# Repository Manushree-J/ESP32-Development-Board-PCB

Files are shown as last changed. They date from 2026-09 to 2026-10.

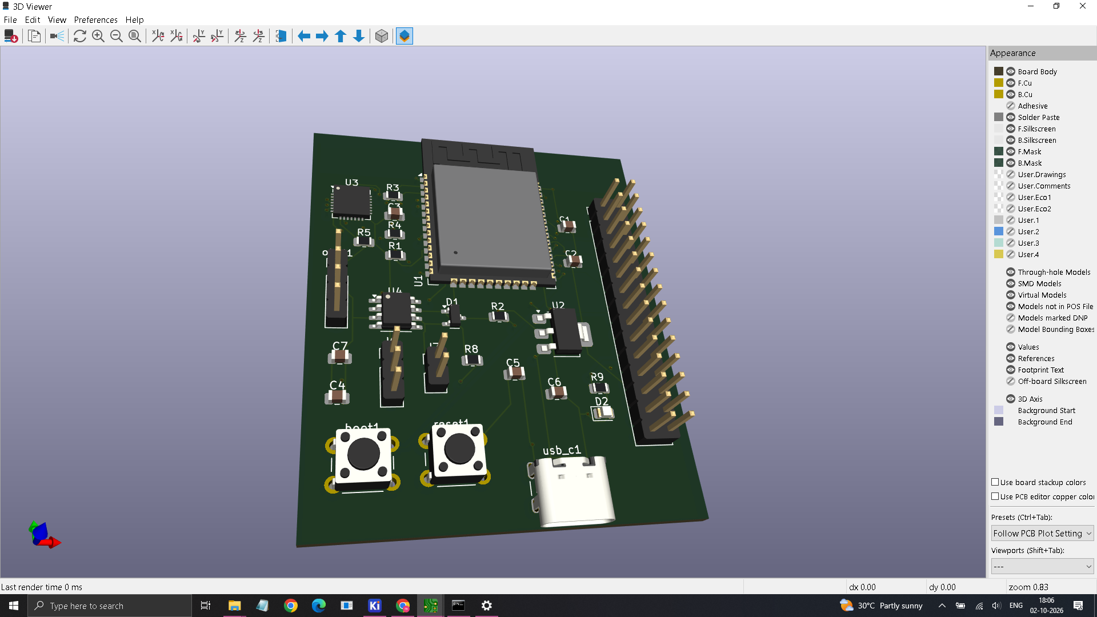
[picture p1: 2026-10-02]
images/3D_view.png

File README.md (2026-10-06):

# ESP32 Development Board — 4-Layer PCB

A custom ESP32 development board designed in KiCad 9, built around the **ESP32-WROOM-32E** module.

The board combines USB programming, regulated power, wireless connectivity, CAN communication, and common embedded interfaces into a compact development platform.

---

## Overview

The ESP32 Development Board is designed as a general-purpose embedded development platform.

The board provides:

- ESP32-WROOM-32E microcontroller module
- Integrated Wi-Fi and Bluetooth
- USB-C interface
- CP2102N USB-to-UART bridge
- AMS1117-3.3 voltage regulator
- I²C interface
- SPI interface
- UART interfaces
- CAN interface
- OLED interface
- Boot and Reset push buttons
- User LED
- 30-pin GPIO expansion header
- Four-layer PCB stackup
- Ground plane on the inner layer
- CAN protection and selectable termination

---

## Hardware Architecture

The main system is centered around the **ESP32-WROOM-32E**.

### Main Blocks

```text
                    ┌──────────────────────┐
                    │      USB-C INPUT     │
                    └──────────┬───────────┘
                               │
                    ┌──────────▼───────────┐
                    │      CP2102N         │
                    │    USB-to-UART       │
                    └──────────┬───────────┘
                               │ UART
                               │
                    ┌──────────▼───────────┐
                    │    ESP32-WROOM-32E   │
                    │                      │
                    │ Wi-Fi + Bluetooth    │
                    │ GPIO / UART / SPI    │
                    │ I²C / CAN           │
                    └───────┬─────┬────────┘
                            │     │
               ┌────────────┘     └─────────────┐
               │                                │
        ┌──────▼──────┐                  ┌──────▼──────┐
        │   OLED/I²C  │                  │    CAN      │
        │             │                  │ SN65HVD230  │
        └─────────────┘                  └──────┬──────┘
                                               │
                                         CANH / CANL

                    ┌──────────────────────┐
                    │    AMS1117-3.3      │
                    │    Power Supply     │
                    └──────────────────────┘

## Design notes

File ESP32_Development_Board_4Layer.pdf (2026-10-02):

ESP32 DEVELOPMENT BOARD | FOUR-LAYER TECHNICAL DATASHEET

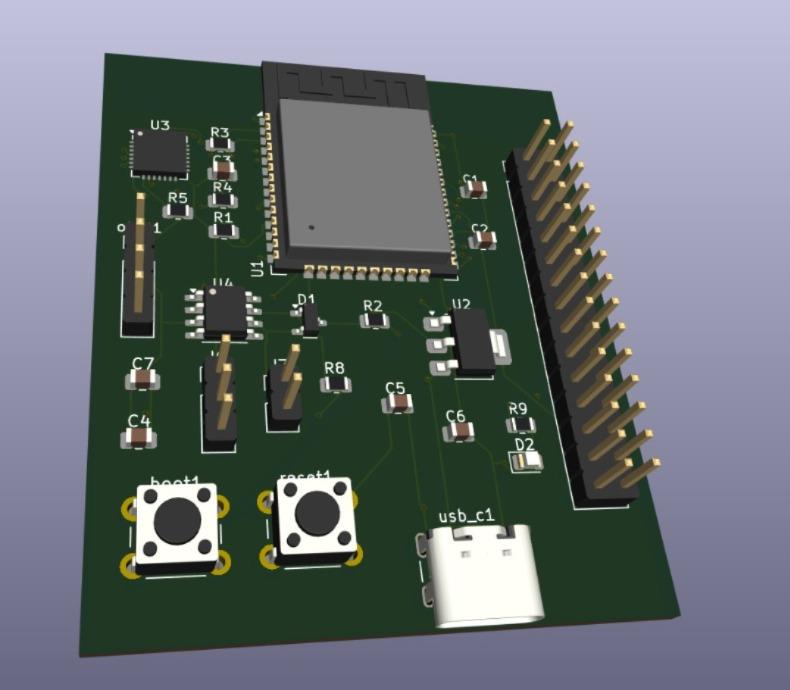
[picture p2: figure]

ESP32 Development Board • Four-Layer PCB

# ESP32 DEVELOPMENT BOARD

## FOUR-LAYER TECHNICAL DATASHEET

A custom embedded development platform with USB programming, wireless connectivity, peripheral interfaces and CAN communication.

# 01 | Product Overview

The ESP32 Development Board is a custom four-layer PCB built around the ESP32-WROOM-32E module. It combines power regulation, USB-to-UART connectivity and common embedded interfaces in a single development platform.

FUNCTION | IMPLEMENTATION
Microcontroller | ESP32-WROOM-32E with integrated Wi-Fi and Bluetooth
USB | USB-C connector with CP2102N USB-to-UART bridge
Power | USB input and AMS1117-3.3 regulator
Display | OLED connector
Communication | UART, SPI, I²C and CAN
CAN hardware | SN65HVD230 transceiver, NUP2105L protection and selectable 120 Ω termination
Expansion | 30-pin, 2.54 mm GPIO header
User controls | Boot and Reset push buttons; user LED

# 02 | Four-Layer PCB Layout

The following views are taken from the current four-layer KiCad PCB design.

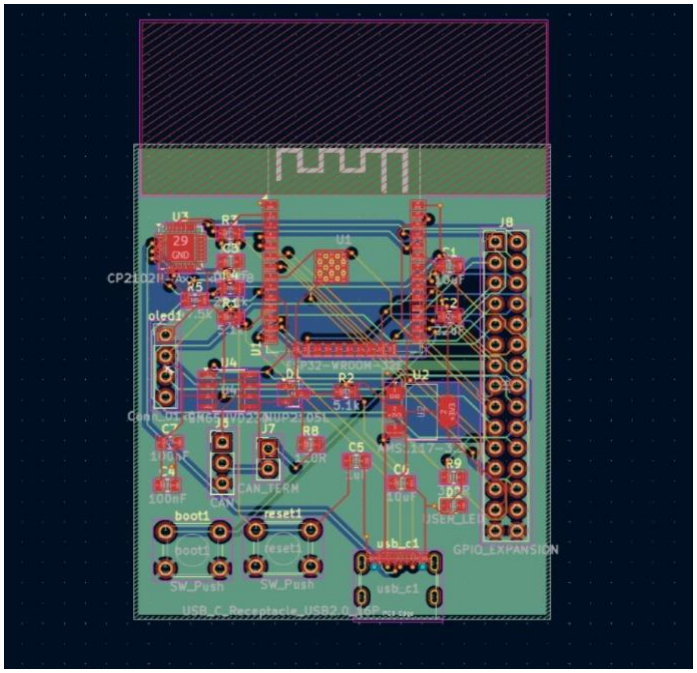
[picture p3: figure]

Figure 1. Current PCB layout with F.Cu selected.

# 03 | F.Cu — Top Copper

Top copper routing and component-side copper features.

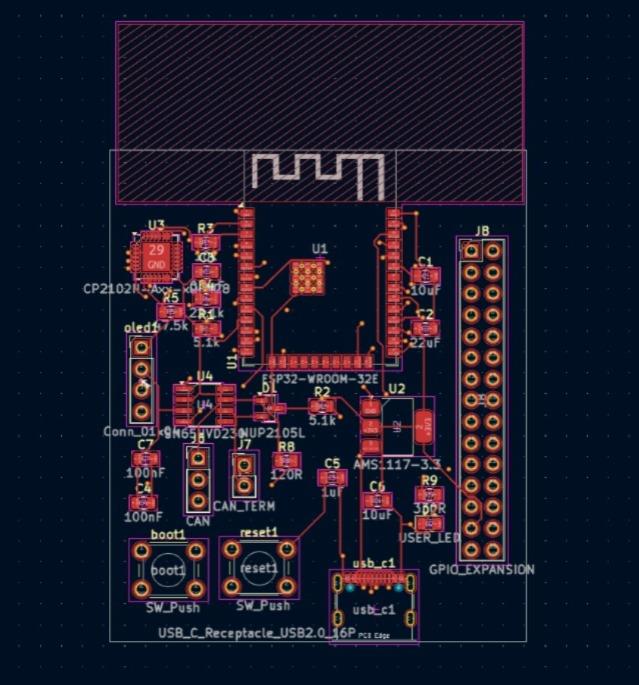
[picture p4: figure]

Current four-layer PCB view.

# 04 | In1.Cu — Inner Ground Layer

Inner copper layer configured as the ground plane.

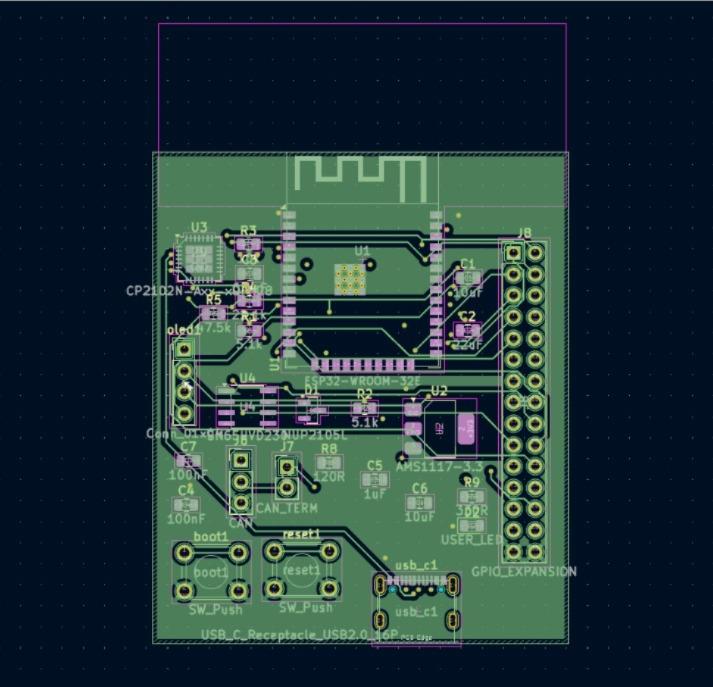
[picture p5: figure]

Current four-layer PCB view.

# 05 | In2.Cu — Inner Routing Layer

Inner copper layer used for additional signal and power routing.

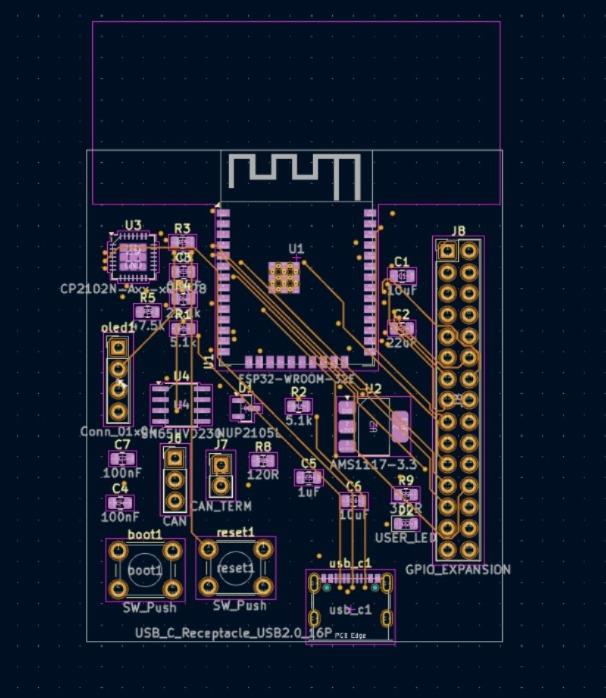
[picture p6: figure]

Current four-layer PCB view.

# 06 | B.Cu — Bottom Copper

Bottom copper routing and ground copper.

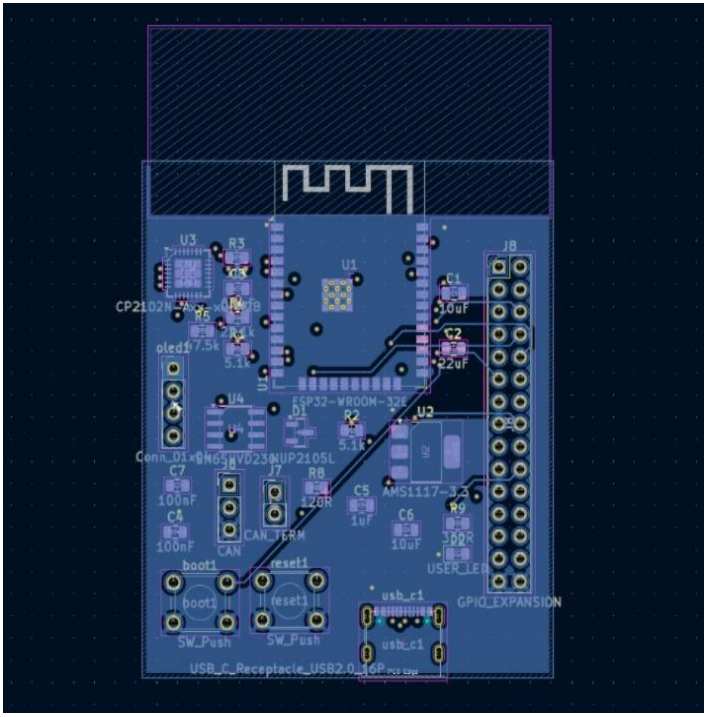
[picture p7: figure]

Current four-layer PCB view.

# 07 | Hardware Architecture

USB-C provides the board input and host connection. The CP2102N provides the USB-to-UART bridge for the ESP32 serial programming path. The AMS1117-3.3 generates the 3.3 V rail. The ESP32 module provides processing and integrated wireless functionality.

## Interface Summary

INTERFACE | SIGNALS / IMPLEMENTATION | NOTES
UART0 | GPIO1 (TX), GPIO3 (RX) | CP2102N serial path
UART2 | GPIO16, GPIO17 | Available through GPIO expansion
I²C | GPIO21 (SDA), GPIO22 (SCL) | OLED / external peripherals
SPI | GPIO18, GPIO19, GPIO23 | Available through GPIO expansion
CAN | GPIO25 / GPIO26; SN65HVD230 | CANH, CANL and GND connector
GPIO | J8, 2×15 header | 26 GPIOs plus power and ground

## Schematic

The schematic is shared by the two-layer and four-layer PCB versions; the four-layer version changes the PCB copper stackup and routing, not the circuit schematic.

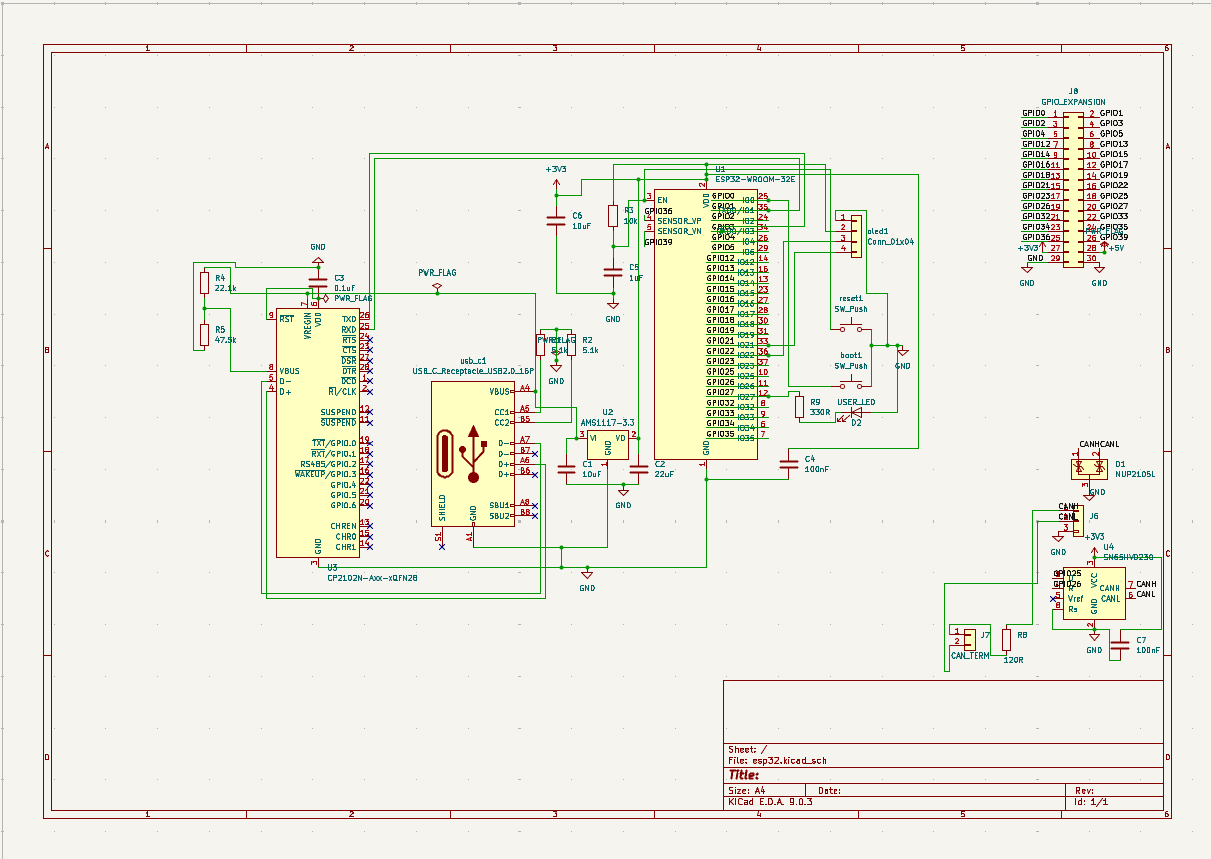
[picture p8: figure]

Figure 2. Shared circuit schematic.

# 08 | GPIO Expansion

J8 is a 30-pin, 2.54 mm-pitch header that exposes the available GPIOs and power connections. GPIO6–GPIO11 are reserved for the module's internal flash interface and are not brought out.

PIN | SIGNAL | PIN | SIGNAL
1 | GPIO0 | 16 | GPIO22
2 | GPIO1 | 17 | GPIO23
3 | GPIO2 | 18 | GPIO25
4 | GPIO3 | 19 | GPIO26
5 | GPIO4 | 20 | GPIO27
6 | GPIO5 | 21 | GPIO32
7 | GPIO12 | 22 | GPIO33
8 | GPIO13 | 23 | GPIO34
9 | GPIO14 | 24 | GPIO35
10 | GPIO15 | 25 | GPIO36
11 | GPIO16 | 26 | GPIO39
12 | GPIO17 | 27 | +3V3
13 | GPIO18 | 28 | +5V
14 | GPIO19 | 29 | GND
15 | GPIO21 | 30 | GND

GPIO34, GPIO35, GPIO36 and GPIO39 are input-only. GPIO0 is used by the boot control circuit. GPIO1 and GPIO3 are shared with the USB-to-UART programming path.

# 09 | Power and CAN

## Power

USB-C supplies the board input. The AMS1117-3.3 regulator generates the 3.3 V rail. Local capacitors provide regulator and device decoupling.

REFERENCE | VALUE / DEVICE | FUNCTION
U2 | AMS1117-3.3 | 3.3 V regulator
C1 | 1 µF | Regulator input-side capacitance
C2 | 22 µF | Regulator output-side bulk capacitance
C4 | 100 nF | ESP32/local decoupling
C6 | 10 µF | Local bulk decoupling
C7 | 100 nF | CAN transceiver decoupling

## CAN Interface

The CAN interface uses an SN65HVD230 transceiver connected to the ESP32 through GPIO25 and GPIO26. CANH and CANL are available at the external CAN connector. A NUP2105L device provides CAN-line protection.

REFERENCE | DEVICE / VALUE | FUNCTION
U4 | SN65HVD230 | CAN physical-layer transceiver
NUP2105L | Protection device | CANH / CANL protection
R8 | 120 Ω | Termination resistor
J7 | CAN_TERM | Selectable termination jumper
J6 | CAN connector | CANH / CANL / GND

When the termination jumper is installed, the 120 Ω resistor is connected between CANH and CANL. The transceiver RS pin is tied to GND for high-speed mode; Vref is left floating.

# 10 | PCB Stackup & Design Status

COPPER LAYER | ROLE
F.Cu | Top copper — component-side routing
In1.Cu | Inner copper — GND plane
In2.Cu | Inner copper — additional signal/power routing
B.Cu | Bottom copper — routing and GND copper zone

Configured board thickness: 1.6 mm. Copper thickness: 0.035 mm per copper layer.

## Design Verification

ITEM | RECORDED STATUS
Schematic ERC | Completed; no errors or warnings reported
PCB connectivity | 0 unconnected items; 0 unrouted connections
Copper zones | Filled
Hardware validation | Fabrication and physical testing have not been performed

## Document Information

FIELD | VALUE
Project | ESP32 Development Board
MCU module | ESP32-WROOM-32E
EDA tool | KiCad 9
PCB version | Four-layer
Schematic | Shared with two-layer version
Repository | github.com/Manushree-J/ESP32-Development-Board-PCB

This datasheet documents the PCB design. Electrical performance and operation should be confirmed through fabrication and hardware testing.

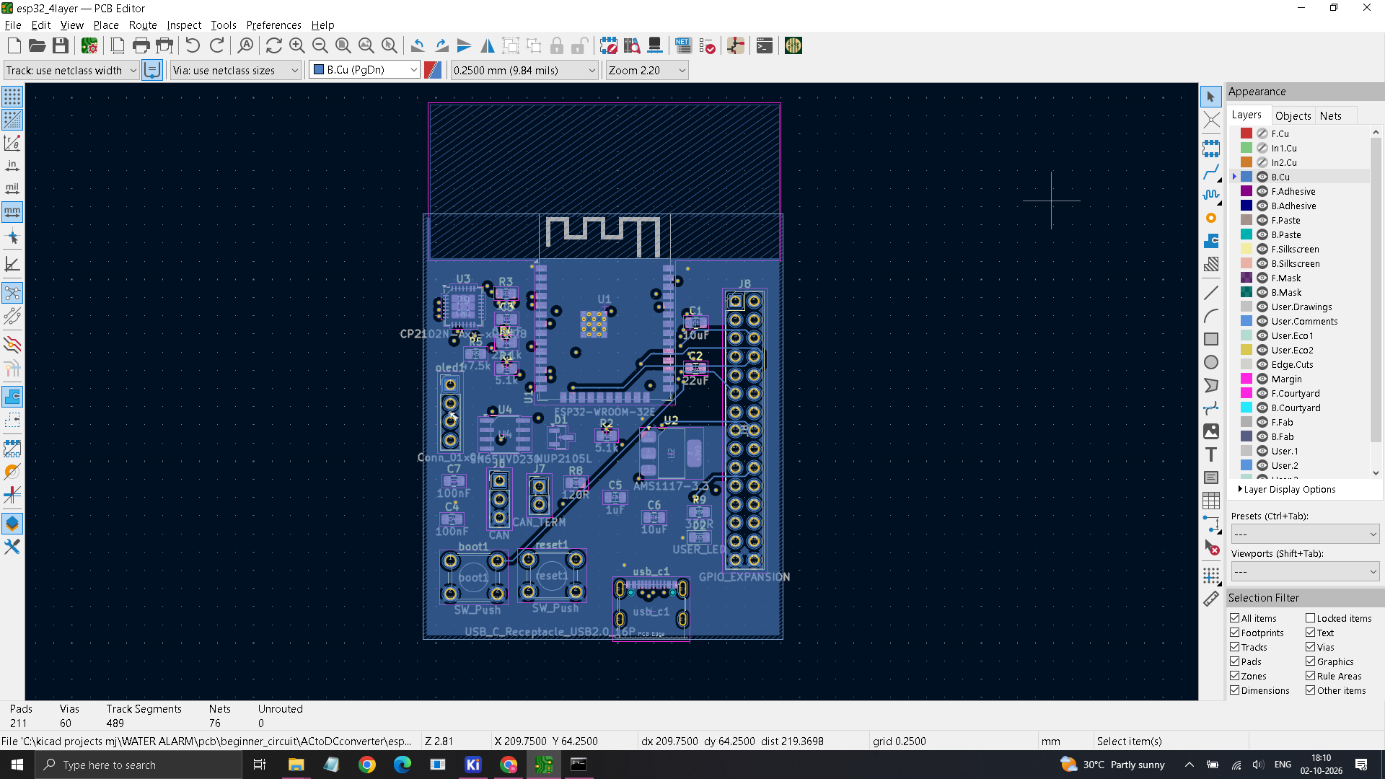
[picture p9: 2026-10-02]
images/bottom_layer.png

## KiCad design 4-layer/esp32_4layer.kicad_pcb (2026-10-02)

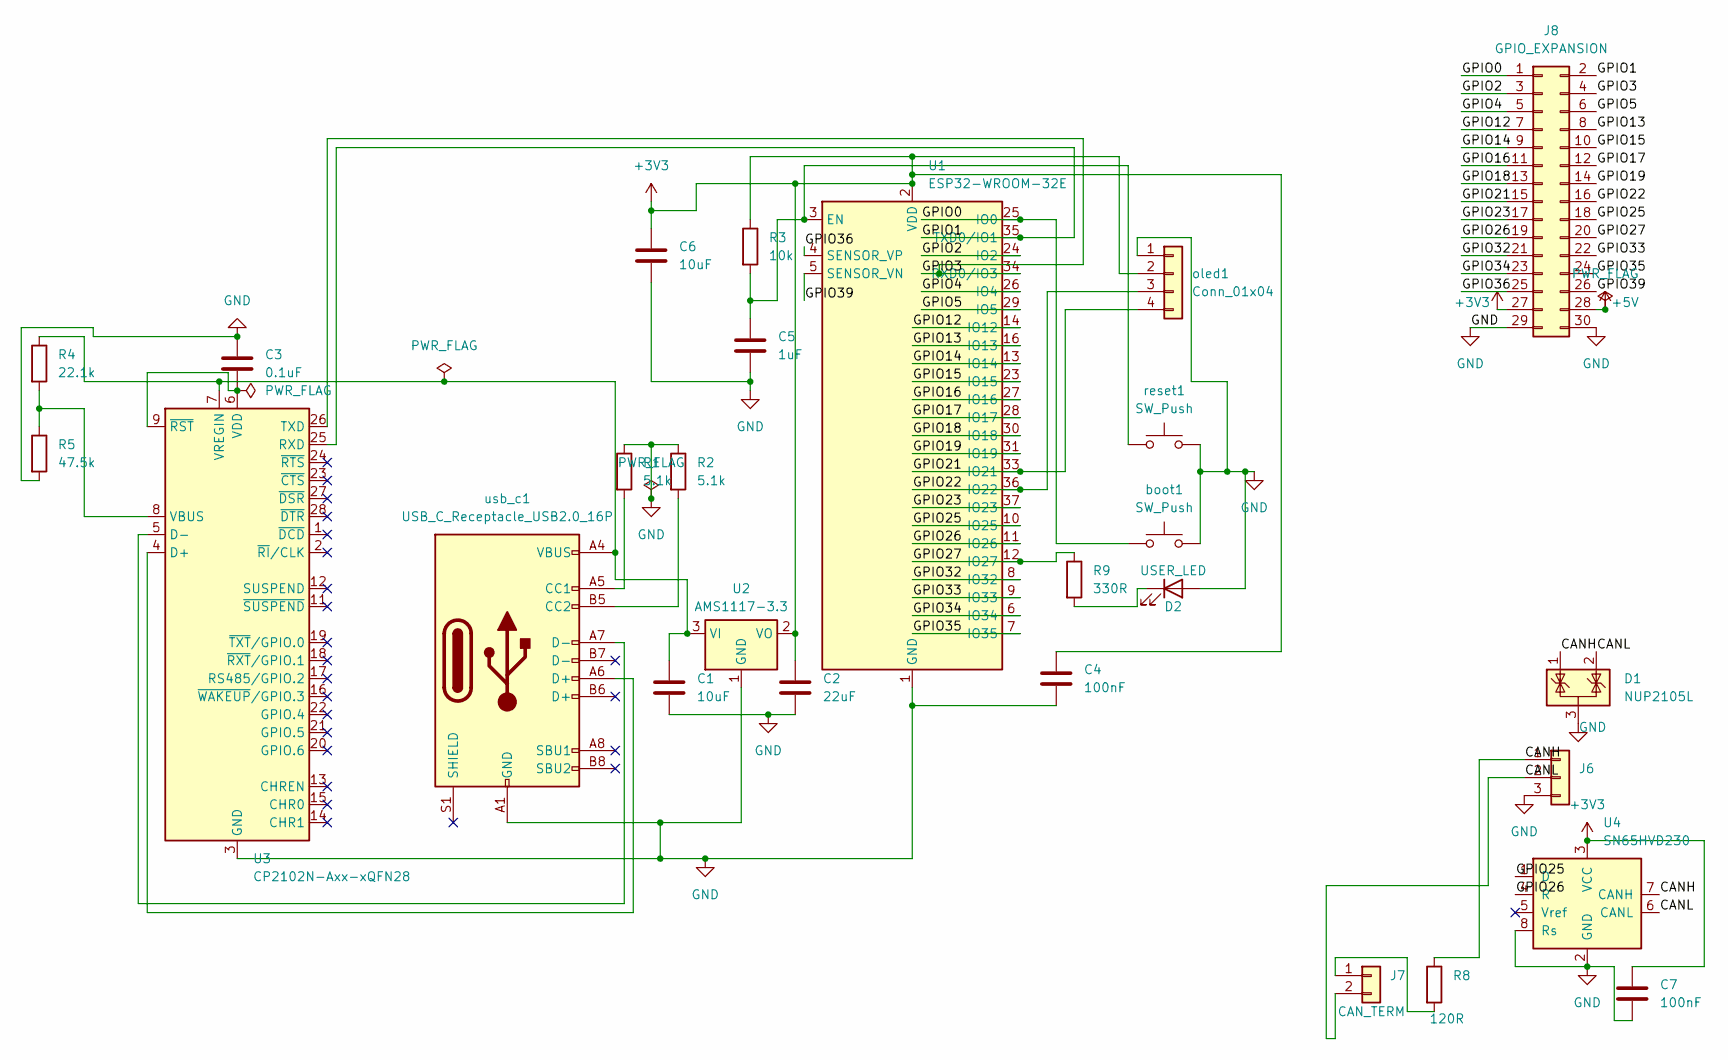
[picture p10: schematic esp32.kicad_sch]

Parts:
C1, C6: 10uF; C_0805_2012Metric
C2: 22uF; C_0805_2012Metric
C3: 0.1uF; C_0805_2012Metric
C4, C7: 100nF; C_0805_2012Metric
C5: 1uF; C_0805_2012Metric
D1: NUP2105L; SOT-23
D2: USER_LED; LED_0805_2012Metric
J6: CAN; PinHeader_1x03_P2.54mm_Vertical
J7: CAN_TERM; PinHeader_1x02_P2.54mm_Vertical
J8: GPIO_EXPANSION; PinHeader_2x15_P2.54mm_Vertical
R1, R2: 5.1k; R_0805_2012Metric
R3: 10k; R_0805_2012Metric
R4: 22.1k; R_0805_2012Metric
R5: 47.5k; R_0805_2012Metric
R8: 120R; R_0805_2012Metric
R9: 330R; R_0805_2012Metric
U1: ESP32-WROOM-32E
U2: AMS1117-3.3; SOT-223-3_TabPin2
U3: CP2102N-Axx-xQFN28; QFN-28-1EP_5x5mm_P0.5mm_EP3.35x3.35mm
U4: SN65HVD230; SOIC-8_3.9x4.9mm_P1.27mm
boot1: SW_Push; SW_PUSH_6mm
oled1: Conn_01x04; PinHeader_1x04_P2.54mm_Vertical
reset1: SW_Push; SW_PUSH_6mm
usb_c1: USB_C_Receptacle_USB2.0_16P; USB_C_Receptacle_GCT_USB4105-xx-A_16P_TopMnt_Horizontal

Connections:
+3V3: C2.1, C4.1, C6.1, C7.1, J8.27, R3.1, U1.2 (VDD), U2.2 (VO), U4.3 (VCC), oled1.2
+5V: J8.28
/CANH: D1.1 (K), J6.1, R8.1, U4.7 (CANH)
/CANL: D1.2 (K), J6.2, J7.2, U4.6 (CANL)
/GPIO0: J8.1, U1.25 (IO0), boot1.1
/GPIO1: J8.2, U1.35 (TXD0/IO1), U3.25 (RXD)
/GPIO2: J8.3, U1.24 (IO2)
/GPIO3: J8.4, U1.34 (RXD0/IO3), U3.26 (TXD)
/GPIO4: J8.5, U1.26 (IO4)
/GPIO5: J8.6, U1.29 (IO5)
/GPIO12: J8.7, U1.14 (IO12)
/GPIO13: J8.8, U1.16 (IO13)
/GPIO14: J8.9, U1.13 (IO14)
/GPIO15: J8.10, U1.23 (IO15)
/GPIO16: J8.11, U1.27 (IO16)
/GPIO17: J8.12, U1.28 (IO17)
/GPIO18: J8.13, U1.30 (IO18)
/GPIO19: J8.14, U1.31 (IO19)
/GPIO21: J8.15, U1.33 (IO21), oled1.4
/GPIO22: J8.16, U1.36 (IO22), oled1.3
/GPIO23: J8.17, U1.37 (IO23)
/GPIO25: J8.18, U1.10 (IO25), U4.1 (D)
/GPIO26: J8.19, U1.11 (IO26), U4.4 (R)
/GPIO27: J8.20, R9.1, U1.12 (IO27)
/GPIO32: J8.21, U1.8 (IO32)
/GPIO33: J8.22, U1.9 (IO33)
/GPIO34: J8.23, U1.6 (IO34)
/GPIO35: J8.24, U1.7 (IO35)
/GPIO36: J8.25, U1.4 (SENSOR_VP)
/GPIO39: J8.26, U1.5 (SENSOR_VN)
GND: C1.2, C2.2, C3.1, C4.2, C5.2, C6.2, C7.2, D1.3 (A), D2.2 (A), J6.3, J8.29, J8.30, R1.1, R2.1, R5.2, U1.1 (GND), U1.15 (GND), U1.38 (GND), U1.39 (GND), U2.1 (GND), U3.3 (GND), U3.29 (GND), U4.2 (GND), U4.8 (Rs), boot1.2, oled1.1, reset1.2, usb_c1.A1 (GND), usb_c1.A12 (GND), usb_c1.B1 (GND), usb_c1.B12 (GND)
unnamed: D2.1 (K), R9.2
unnamed: J7.1, R8.2
unnamed: C5.1, R3.2, U1.3 (EN), reset1.1
unnamed: C1.1, R4.1, U2.3 (VI), U3.7 (VREGIN), usb_c1.A4 (VBUS), usb_c1.A9 (VBUS), usb_c1.B4 (VBUS), usb_c1.B9 (VBUS)
unnamed: U3.4 (D+), usb_c1.A6 (D+)
unnamed: U3.5 (D-), usb_c1.A7 (D-)
unnamed: R4.2, R5.1, U3.8 (VBUS)
unnamed: C3.2, U3.6 (VDD), U3.9 (~RST)
unnamed: R1.2, usb_c1.A5 (CC1)
unnamed: R2.2, usb_c1.B5 (CC2)

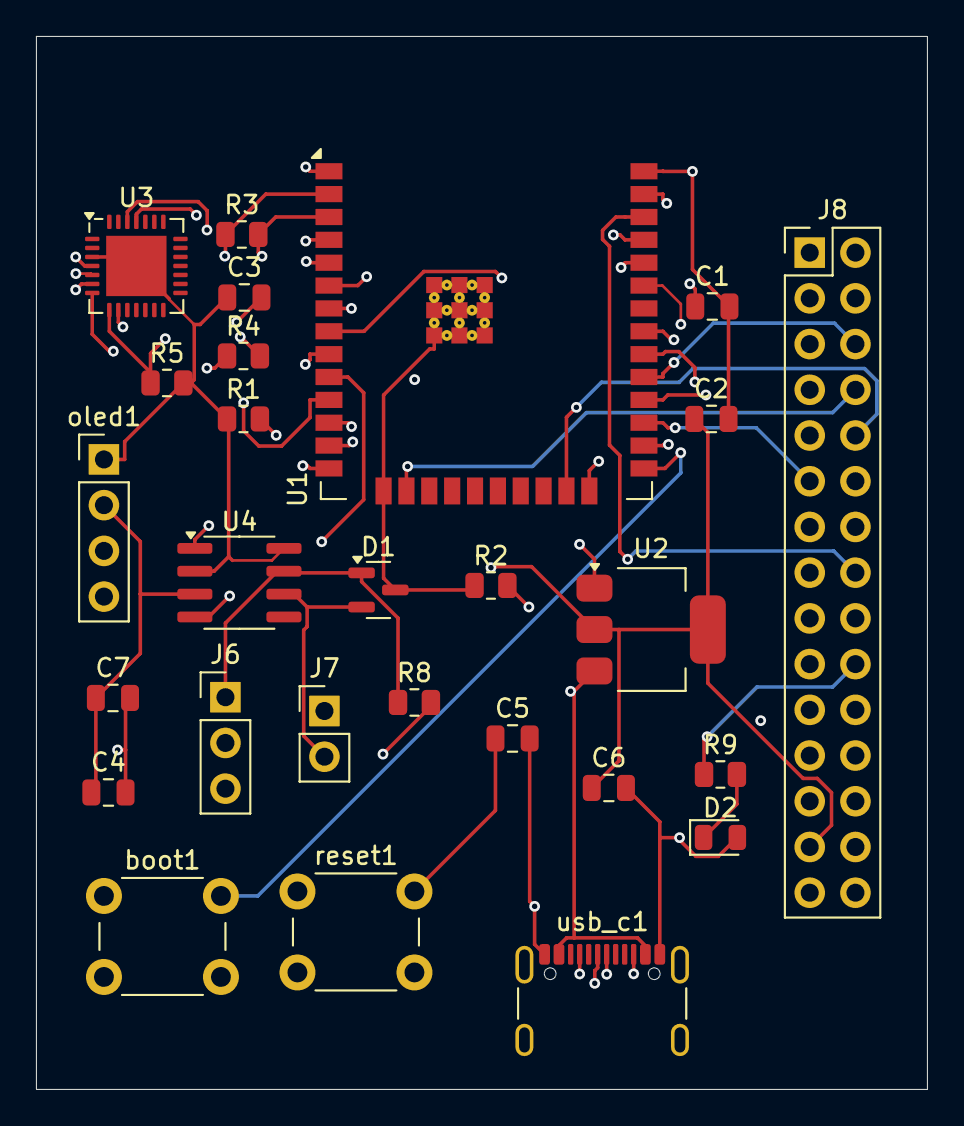
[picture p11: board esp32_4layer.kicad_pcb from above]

Board: 4 copper layers, 49.5 x 58.5 mm, 27 parts (0 on the bottom side), 40 nets.

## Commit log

2026-08-31 Add initial ESP32 PCB design
    [esp32.kicad_pcb, esp32.kicad_sch]
2026-08-31 Add PCB design images
2026-09-02 Updated PCB Designs
    [esp32.kicad_pcb, esp32.kicad_sch]
2026-09-02 Updated PCB design pictures
2026-10-02 Add README for 2-layer PCB design
2026-10-02 Add README for four-layer PCB design
2026-10-02 Add README for ESP32 schematic
2026-10-02 Add README for 4-layer PCB images
2026-10-06 Revise README for ESP32 Development Board
    Updated project details and structure in README.
2026-10-21 Add enhanced 4-layer ESP32 PCB design files
2026-10-21 4- layer pcb images
2026-10-21 2-Layer pcb images
2026-10-21 Enhanced 4_layer pcb placement images
2026-10-21 Enhance README with detailed project information
    Expanded the README to provide detailed information about the ESP32 development board, including features, PCB stackup, design tools, workflow, project files, learning outcomes, and project status.
2026-10-21 Enhance README with project details and workflow
    Added detailed project overview, features, hardware design, PCB stackup, design tools, workflow, verification, repository contents, project status, and future improvements for the ESP32 development b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
2026-10-21 Enhance README with project details and objectives
    Expanded project documentation to include detailed descriptions of design evolution, hardware architecture, and engineering approaches for the ESP32 development board.
2026-10-22 Update 3D PCB views section in README
    Removed the table structure for 3D PCB views and replaced it with a single image link.
